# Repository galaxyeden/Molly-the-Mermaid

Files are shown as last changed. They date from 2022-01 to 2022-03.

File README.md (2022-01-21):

# Molly the Mermaid

Molly the Mermaid is my 2022 badge project, following on from 2020's [Candy the Catacorn](https://galaxyallie.space/Candy-the-Catacorn/).

- Mermaid tail PCB intended to be used with a hand-made mermaid body for customization.
- Raspberry Pi Pico used as a module to provide much functionality and enable easy assembly for beginners
- Intended completion April 2022
- Bright shiny things
- Gaming controls!
- [v1.69bis](https://hackaday.com/2019/03/20/introducing-the-shitty-add-on-v1-69bis-standard/) compliant-ish

## Bill of Materials

| Component | Manufacturer | Qty |
|---|---|-----|
| This board | Whoever you choose | 1 |
| Raspberry Pi Pico | Raspberry Pi | 1 |
| S2B-PH-SM4-TB(LF)(SN) | JST | 1 |
| 0.1uF 0805 Capacitor | Generic | 5 |
| WS2812b | WorldSemi | 5 |
| LED 0805 | Generic | 10  |
| DSS14UTR | SMC Diode Solutions | 1 |
| 470 Ohm 0805 Resistor | Generic | 11  |
| TL3342 Switch (or equivalent) | E-Switch (or generic) | 6 |
| 2x3 2.54mm pin socket connector | Generic | 1 |

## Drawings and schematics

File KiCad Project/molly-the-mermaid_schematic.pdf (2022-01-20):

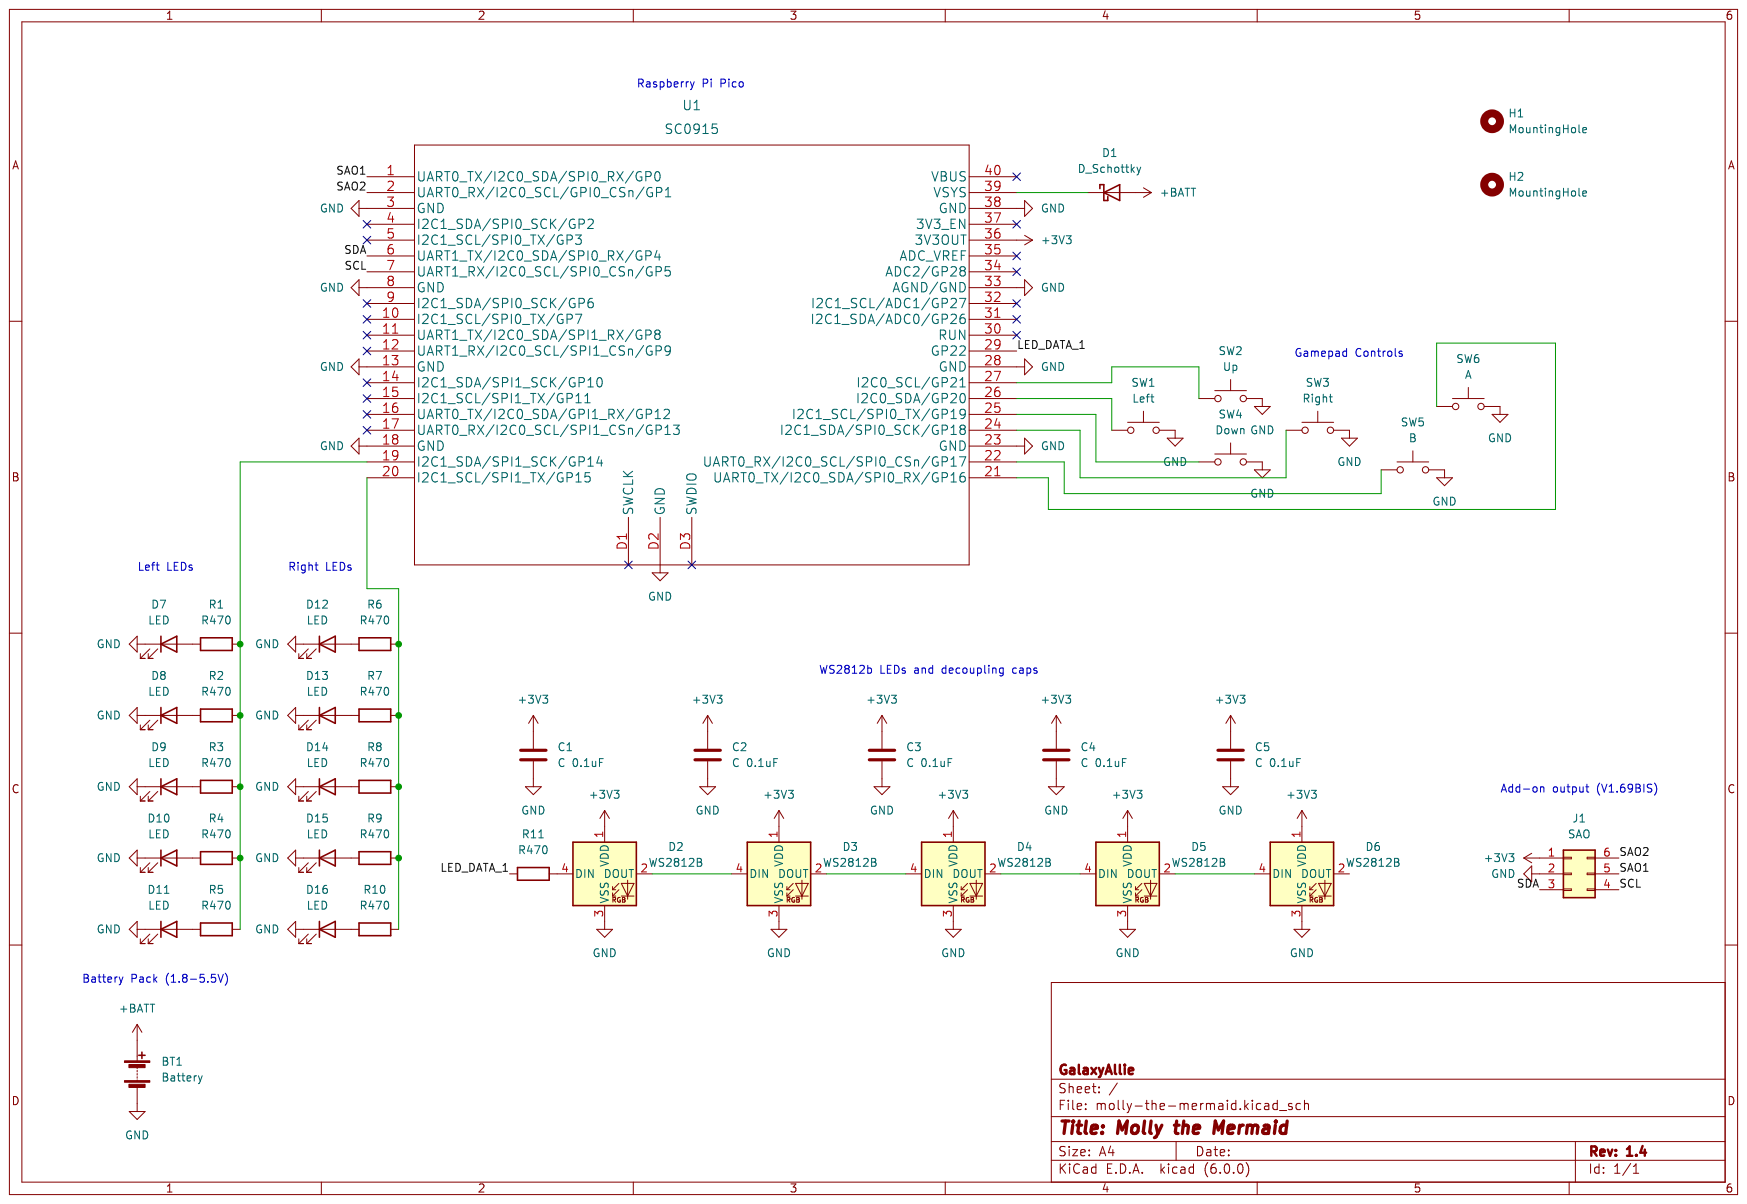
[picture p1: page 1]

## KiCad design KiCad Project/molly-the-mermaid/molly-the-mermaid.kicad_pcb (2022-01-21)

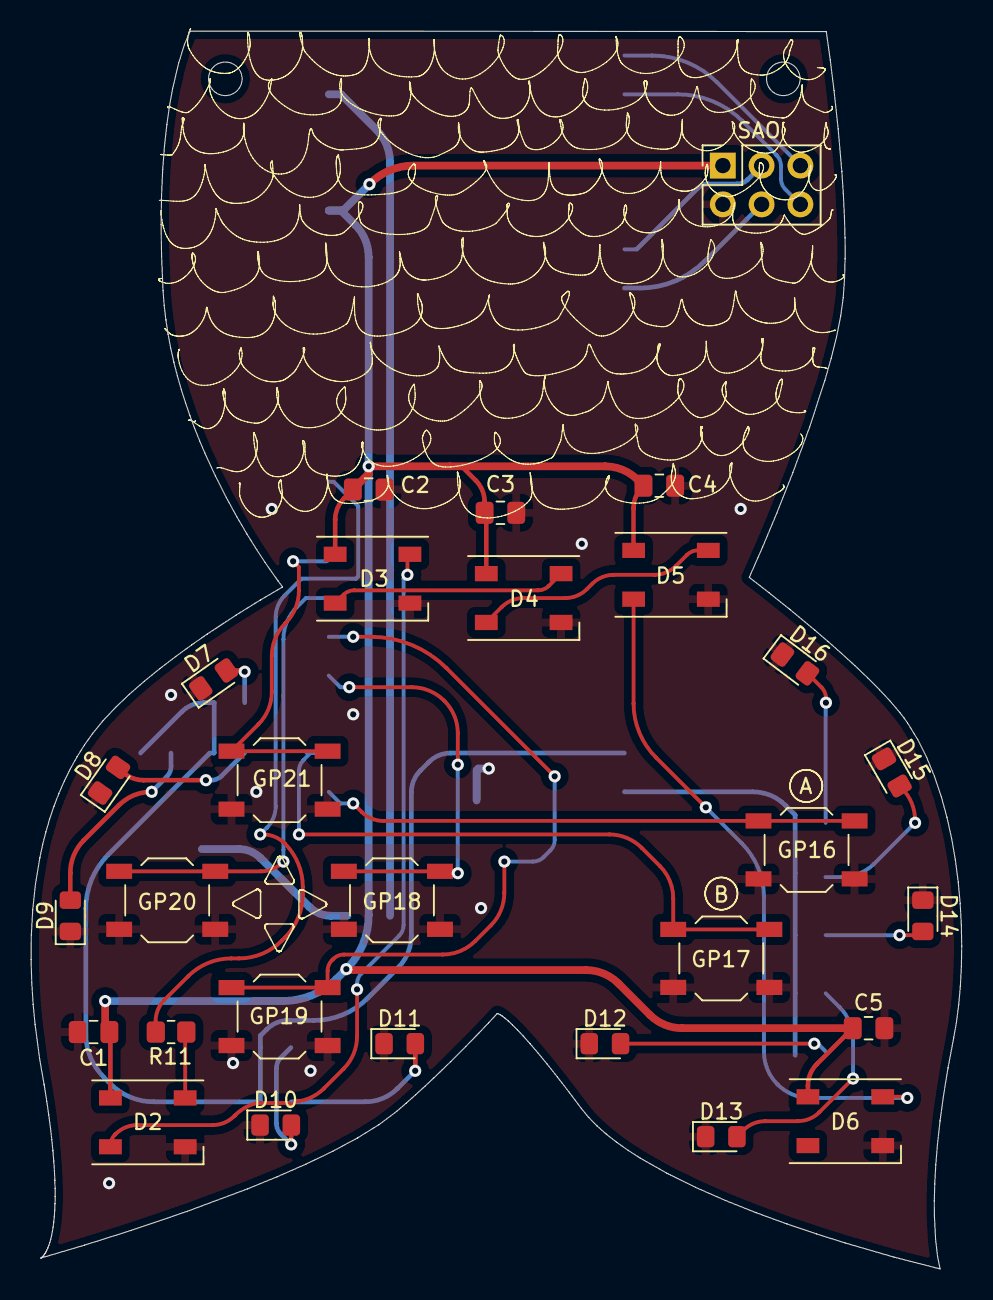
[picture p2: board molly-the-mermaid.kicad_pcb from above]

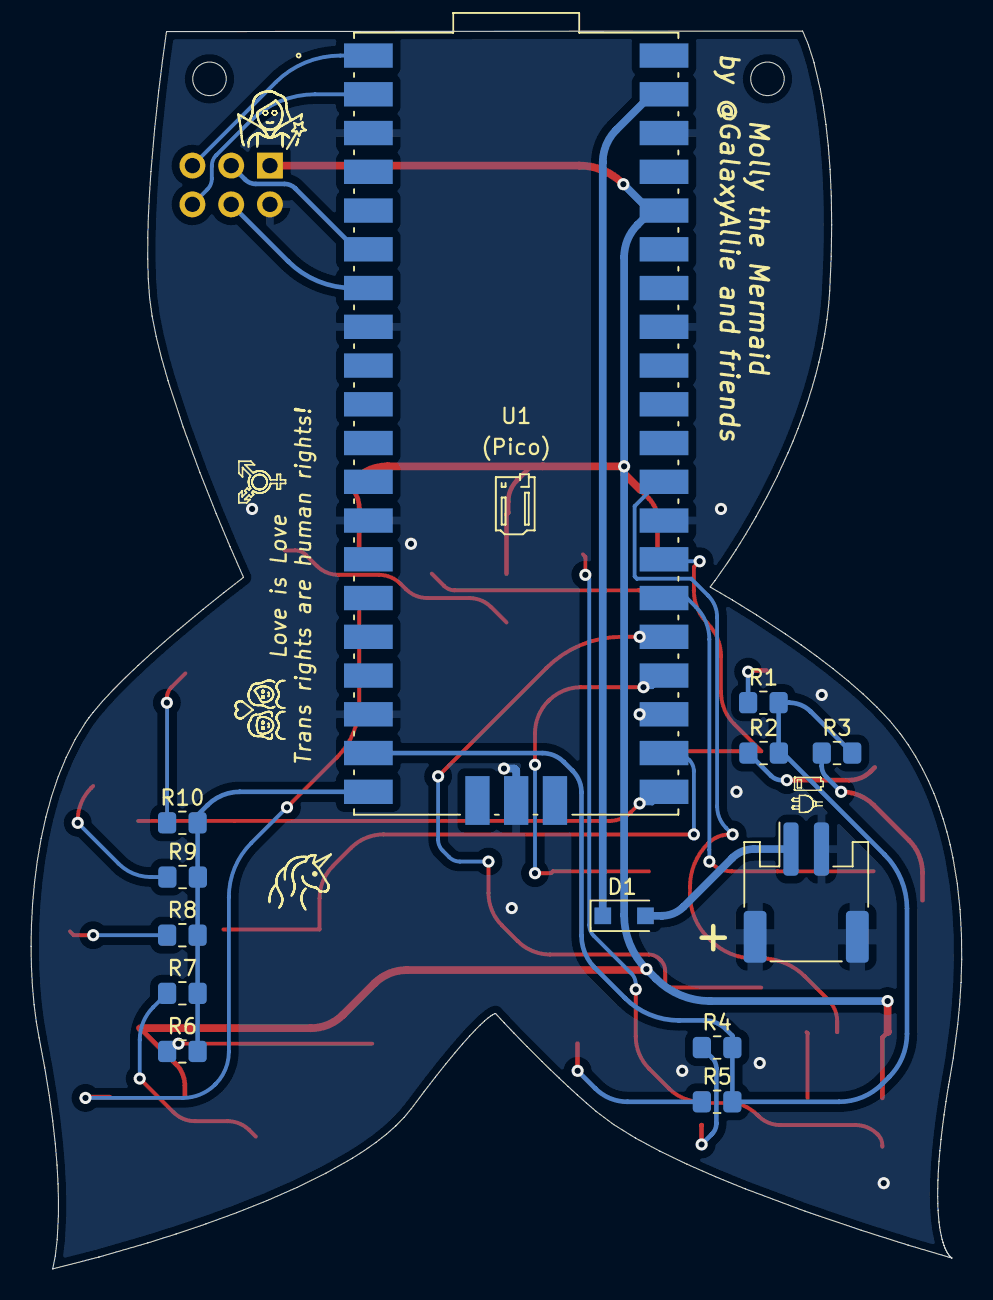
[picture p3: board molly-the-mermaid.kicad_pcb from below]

Board: 2 copper layers, 61.0 x 81.1 mm, 43 parts (13 on the bottom side), 32 nets.

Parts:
A: A; SW_SPST_TL3342
B: B; SW_SPST_TL3342
Battery: Battery; JST_PH_S2B-PH-SM4-TB_1x02-1MP_P2.00mm_Horizontal
C1, C2, C3, C4, C5: C; C_0805_2012Metric_Pad1.18x1.45mm_HandSolder
D1: D_Schottky; D_SOD-123F
D2, D3, D4, D5, D6: WS2812B; LED_WS2812B_PLCC4_5.0x5.0mm_P3.2mm
D7, D8, D9, D10, D11, D12, D13, D14, D15, D16: LED; LED_0805_2012Metric_Pad1.15x1.40mm_HandSolder
Down: Down; SW_SPST_TL3342
H1, H2: MountingHole; MountingHole_2.2mm_M2
Left: Left; SW_SPST_TL3342
R1, R2, R3, R4, R5, R6, R7, R8, R9, R10, R11: R; R_0805_2012Metric_Pad1.20x1.40mm_HandSolder
Right: Right; SW_SPST_TL3342
SAO: SAO; PinSocket_2x03_P2.54mm_Vertical
U1: (Pico); SC0915-No test pads
Up: Up; SW_SPST_TL3342

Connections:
+3V3: C1.1, C2.1, C3.1, C4.1, C5.1, D2.1 (VDD), D3.1 (VDD), D4.1 (VDD), D5.1 (VDD), D6.1 (VDD), SAO.1, U1.36 (3V3OUT)
+BATT: Battery.1 (+), D1.2 (A)
/LED_DATA_1: R11.1, U1.29 (GP22)
/SAO1: SAO.5, U1.1 (UART0_TX/I2C0_SDA/SPI0_RX/GP0)
/SAO2: SAO.6, U1.2 (UART0_RX/I2C0_SCL/GPI0_CSn/GP1)
/SCL: SAO.4, U1.7 (UART1_RX/I2C0_SCL/SPI0_CSn/GP5)
/SDA: SAO.3, U1.6 (UART1_TX/I2C0_SDA/SPI0_RX/GP4)
GND: A.2, B.2, Battery.2 (-), Battery.MP, C1.2, C2.2, C3.2, C4.2, C5.2, D2.3 (VSS), D3.3 (VSS), D4.3 (VSS), D5.3 (VSS), D6.3 (VSS), D7.1 (K), D8.1 (K), D9.1 (K), D10.1 (K), D11.1 (K), D12.1 (K), D13.1 (K), D14.1 (K), D15.1 (K), D16.1 (K), Down.2, Left.2, Right.2, SAO.2, U1.3 (GND), U1.8 (GND), U1.13 (GND), U1.18 (GND), U1.23 (GND), U1.28 (GND), U1.33 (AGND/GND), U1.38 (GND), U1.D2 (GND), Up.2
unnamed: D1.1 (K), U1.39 (VSYS)
unnamed: D2.2 (DOUT), D3.4 (DIN)
unnamed: D2.4 (DIN), R11.2
unnamed: D3.2 (DOUT), D4.4 (DIN)
unnamed: D4.2 (DOUT), D5.4 (DIN)
unnamed: D5.2 (DOUT), D6.4 (DIN)
unnamed: D7.2 (A), R1.1
unnamed: D8.2 (A), R2.1
unnamed: D9.2 (A), R3.1
unnamed: D10.2 (A), R4.1
unnamed: D11.2 (A), R5.1
unnamed: D12.2 (A), R6.1
unnamed: D13.2 (A), R7.1
unnamed: D14.2 (A), R8.1
unnamed: D15.2 (A), R9.1
unnamed: D16.2 (A), R10.1
unnamed: R1.2, R2.2, R3.2, R4.2, R5.2, U1.19 (I2C1_SDA/SPI1_SCK/GP14)
unnamed: R6.2, R7.2, R8.2, R9.2, R10.2, U1.20 (I2C1_SCL/SPI1_TX/GP15)
unnamed: Left.1, U1.26 (I2C0_SDA/GP20)
unnamed: U1.27 (I2C0_SCL/GP21), Up.1
unnamed: Right.1, U1.24 (I2C1_SDA/SPI0_SCK/GP18)
unnamed: Down.1, U1.25 (I2C1_SCL/SPI0_TX/GP19)
unnamed: B.1, U1.22 (UART0_RX/I2C0_SCL/SPI0_CSn/GP17)
unnamed: A.1, U1.21 (UART0_TX/I2C0_SDA/SPI0_RX/GP16)

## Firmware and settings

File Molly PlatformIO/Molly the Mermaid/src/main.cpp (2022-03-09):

#include <Arduino.h>
#include <Adafruit_NeoPixel.h>

#define LED_COUNT 30
#define LED_PIN 22
#define LED_LEFT 14
#define LED_RIGHT 15

Adafruit_NeoPixel strip(LED_COUNT, LED_PIN, NEO_GRB + NEO_KHZ800);

void setup() {
  strip.begin();
  strip.show();
  strip.setBrightness(10);
  pinMode(LED_LEFT, OUTPUT);
  pinMode(LED_RIGHT, OUTPUT);
}

void rainbow(int wait) {
  for(long firstPixelHue = 0; firstPixelHue < 5*65536; firstPixelHue += 256) {
    for(int i=0; i<strip.numPixels(); i++) { 
      int pixelHue = firstPixelHue + (i * 65536L / strip.numPixels());
      strip.setPixelColor(i, strip.gamma32(strip.ColorHSV(pixelHue)));
    }
    strip.show();
    delay(wait);
  }
}

void loop() {
  analogWrite(LED_RIGHT, 20);
  delay(1000);
  analogWrite(LED_LEFT, 20);
  rainbow(20);
}

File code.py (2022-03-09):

import time
import board
from rainbowio import colorwheel
import neopixel
import digitalio
import pwmio

pixel_pin = board.GP22
led_left = pwmio.PWMOut(board.GP14)
led_right = pwmio.PWMOut(board.GP15)
body_pin_1 = board.GP0
body_pin_2 = board.GP1
button_up = digitalio.DigitalInOut(board.GP21)
button_down = digitalio.DigitalInOut(board.GP19)
button_left = digitalio.DigitalInOut(board.GP20)
button_right = digitalio.DigitalInOut(board.GP18)
button_a = digitalio.DigitalInOut(board.GP16)
button_b = digitalio.DigitalInOut(board.GP17)
raspberry_led = digitalio.DigitalInOut(board.GP25)

raspberry_led.direction = digitalio.Direction.OUTPUT

button_a.direction = digitalio.Direction.INPUT
button_b.direction = digitalio.Direction.INPUT
button_up.direction = digitalio.Direction.INPUT
button_down.direction = digitalio.Direction.INPUT
button_left.direction = digitalio.Direction.INPUT
button_right.direction = digitalio.Direction.INPUT

button_a.pull = digitalio.Pull.UP
button_b.pull = digitalio.Pull.UP
button_up.pull = digitalio.Pull.UP
button_down.pull = digitalio.Pull.UP
button_left.pull = digitalio.Pull.UP
button_right.pull = digitalio.Pull.UP

num_pixels = 5
eyes_count = 2
active_pixel = 2

pixels = neopixel.NeoPixel(pixel_pin, num_pixels, brightness=0.1, auto_write=False)
eyes = neopixel.NeoPixel(body_pin_1, eyes_count, brightness=0.1, auto_write=False)

def rainbow_cycle(wait):
    for j in range(255):
        for i in range(num_pixels):
            rc_index = (i * 256 // num_pixels) + j
            pixels[i] = colorwheel(rc_index & 255)
        pixels.show()
        if button_a.value:
            break
        time.sleep(wait)

while True:
    led_left.duty_cycle = 200
    led_right.duty_cycle = 200
    eyes.fill([0, 80, 140])
    eyes.show()
    raspberry_led.value = False
    if button_up.value == False:
        active_pixel -= 1
        if active_pixel < 0:
            active_pixel = 4
    if button_down.value == False:
        active_pixel += 1
        if active_pixel > 4:
            active_pixel = 0
    pixels.fill([75, 0, 55])    
    pixels[active_pixel] = ([0, 80, 140])
    pixels.show()
    while button_left.value == False:
        led_left.duty_cycle = 15000
    while button_right.value == False:
        led_right.duty_cycle = 15000
    while button_b.value == False:
        eyes.fill([30, 0, 150])
        eyes.show()
        raspberry_led.value = True
    while button_a.value == False:
        rainbow_cycle(0.1)
    time.sleep(0.1)

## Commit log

2022-01-19 Create KiCad Project
    [molly-the-mermaid.kicad_pcb, molly-the-mermaid.kicad_sch]
2022-01-19 Customized footprint
    [molly-the-mermaid.kicad_sch]
2022-01-19 First draft
    [molly-the-mermaid.kicad_sch]
2022-01-19 1.0 schematic
    [molly-the-mermaid.kicad_sch]
2022-01-19 fixed 3V3
    [molly-the-mermaid.kicad_sch]
2022-01-20 board draft
    [molly-the-mermaid.kicad_pcb, molly-the-mermaid.kicad_sch]
2022-01-20 connected grounds
    [molly-the-mermaid.kicad_pcb]
2022-01-20 another missing ground
    [molly-the-mermaid.kicad_pcb]
2022-01-20 cleared some DRC errors
    [molly-the-mermaid.kicad_pcb]
2022-01-20 add mounting holes
    [molly-the-mermaid.kicad_pcb, molly-the-mermaid.kicad_sch]
2022-01-20 Added component values to schematic
    [molly-the-mermaid.kicad_pcb, molly-the-mermaid.kicad_sch]
2022-01-20 Board draft 2
    [molly-the-mermaid.kicad_pcb]
2022-01-20 moved SAO connector up
    [molly-the-mermaid.kicad_pcb]
2022-01-21 Final draft board
    [molly-the-mermaid.kicad_pcb]
2022-01-21 First production run version
    [molly-the-mermaid-B_Cu.gbr, molly-the-mermaid-B_Mask.gbr, molly-the-mermaid-B_Paste.gbr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]
2022-01-21 added pico itself to BOM
2022-03-09 Added CircuitPython code
2022-03-09 Add B button test that doesn't need external neopixels
    [code.py]

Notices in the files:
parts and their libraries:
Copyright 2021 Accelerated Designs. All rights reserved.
